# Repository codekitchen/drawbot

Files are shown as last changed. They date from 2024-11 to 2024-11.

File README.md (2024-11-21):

# Drawbot Remix

For [Recurse F2'24](https://www.recurse.com).

My goal is to build a wall-drawing robot, specifically to draw on our windows with dry-erase markers. This is starting out as a remix of [this drawbot project](https://github.com/andywise/drawbot) with some inspiration from [this other project](https://tinkerlog.com/2011/09/02/der-kritzler/).

I'm using some hardware I already have on hand, and I'm otherwise buying some different hardware from what was used in the original drawbot project, so the project will necessarily branch from the original drawbot project.

I've ended up making my own models for some of the 3D printed parts to match my needs. Those can be found in the [models](models/) folder in parameterized [OpenSCAD](https://openscad.org/) format.

I also ended up writing all my own software for the project, rather than using any of the software from the original drawbot. Just for fun!

## Progress

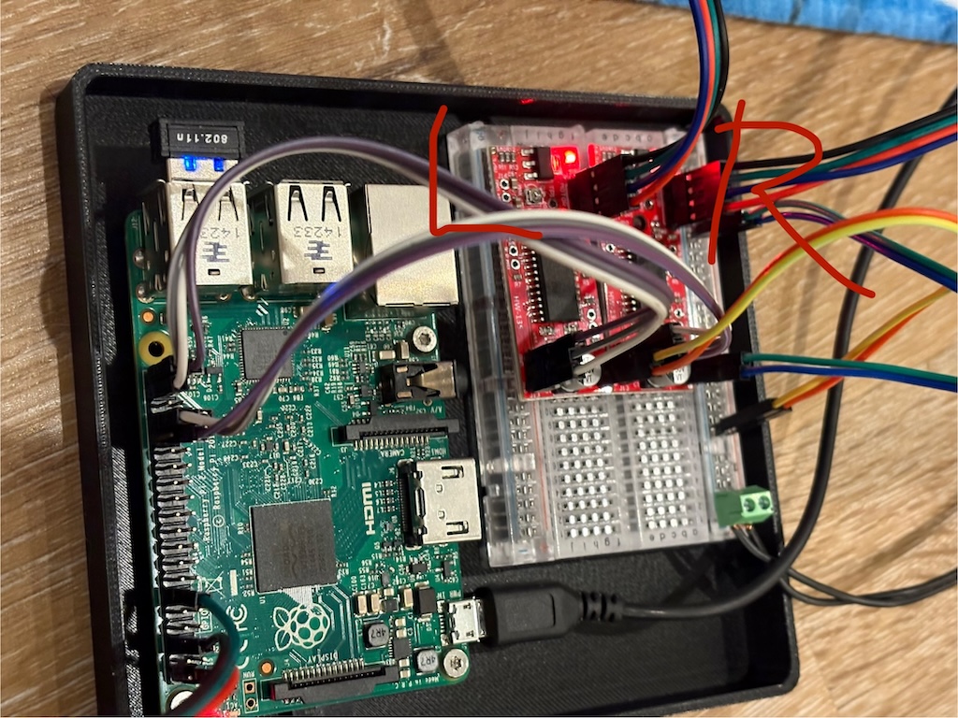
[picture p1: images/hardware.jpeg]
hardware


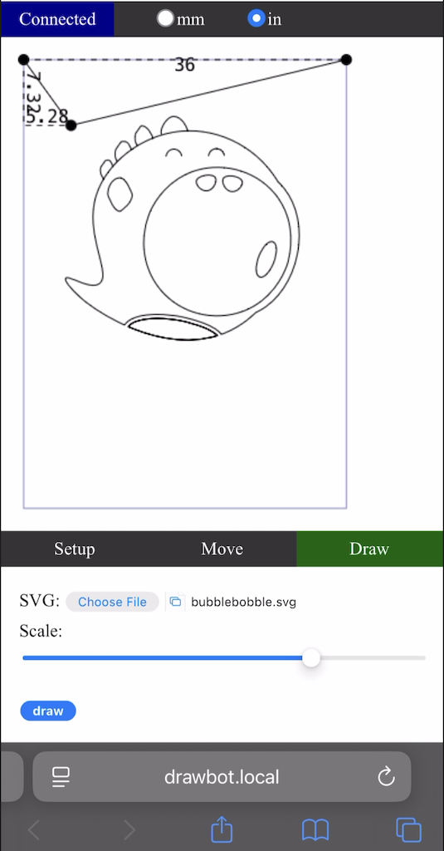
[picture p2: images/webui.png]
ui screenshot


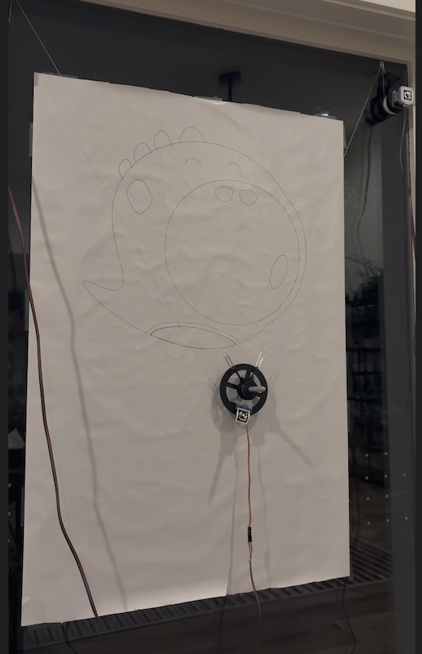
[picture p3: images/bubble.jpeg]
crow on window


I'm keeping a journal in a [separate document](JOURNAL.md).

## Links

- [Drawbot on GitHub](https://github.com/andywise/drawbot)
- [Drawbot assembly details](https://www.instructables.com/Drawbot/)
- [OpenSCAD Cheat Sheet](https://openscad.org/cheatsheet/)
- [NEMA-17 motor dimensions](https://reprap.org/wiki/NEMA_17_Stepper_motor)
- [Hull operations](https://hackaday.com/2018/02/13/openscad-tieing-it-together-with-hull/) for OpenSCAD modeling

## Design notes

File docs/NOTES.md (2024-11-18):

# Setup

1. Attach the motors to the top left/right of the surface using the suction cups.
2. Attach motor cables to controllers and motors.
3. Power up the controllers. WARNING: Don't do this before the cables are attached.
4. Attach the pen gantry to the strings. I like to tie the strings to paper clips and hook the clips to the pen gantry, it's a lot easier to detach after.
5. Attach the servo motor cable.
6. Turn on the pi.
7. Press the "pen up" button in the web ui.
8. Insert the pen so that it just barely isn't touching the surface, then tighten the screw to secure it in place.
9. Start drawing!

# Teardown

Reverse order of setup.

# Apriltag Detection

- [Webcam to JPEG](https://medium.com/@arpit23sh/capturing-webcam-images-using-html-and-javascript-9b8896ef1705)
- [emscripten compiling](https://emscripten.org/docs/getting_started/FAQ.html#faq-dead-code-elimination)
- [focal length](https://www.scantips.com/lights/subjectdistance.html)
-
image 5712 x 4284
focal len equiv: 26
focal len: 5.96
26/5.96 = 4.362 crop factor
35mm = 36 x 24, diagonal 43.2667 mm
43.2667 / 4.362 = 9.919 diagonal mm
diag = sqrt(5712**2+4284**2) = 7140
5712 / 7140 = 0.8
4284 / 7140 = 0.6
sensor width  = 9.919 * 0.8 = 7.93
sensor height = 9.919 * 0.6 = 5.95

focal length in pixels = (image width in pixels) * (focal length in mm) / (CCD width in mm)
fx = 5712 * 5.96 / 7.93 = 4293
fy = 4284 * 5.96 / 5.95 = 4291

# Pen Movement

## Motor Stepping

Spool diameter = 48mm
Spool circumference, distance moved in one full rotation = 48*PI = 150.79
Motor steps per rotation = 1600
Distance per step = 15.708 / 1600 = 0.0098175
Steps per mm = 101.8589

with string = 50*PI = 157

1600 steps = 155mm
Steps per mm = 10

d = 400.05
x = 60.32
y = 88.9

h1 = 107.43
h2 = 351

# new position
x=200
y=90
h1 = 220
h2 = 220

h1' = 220-107 = 113
h2' = 220-351 = -131

250,200
350,400

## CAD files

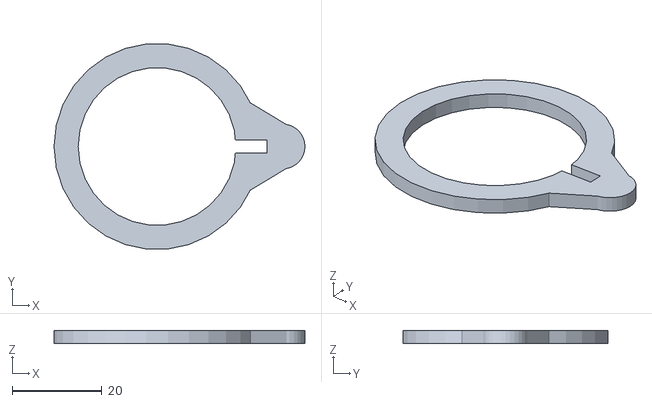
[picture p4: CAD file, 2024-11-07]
models/drawbot_stls/BearingConnector.stl
56.0 x 45.7 x 3.00

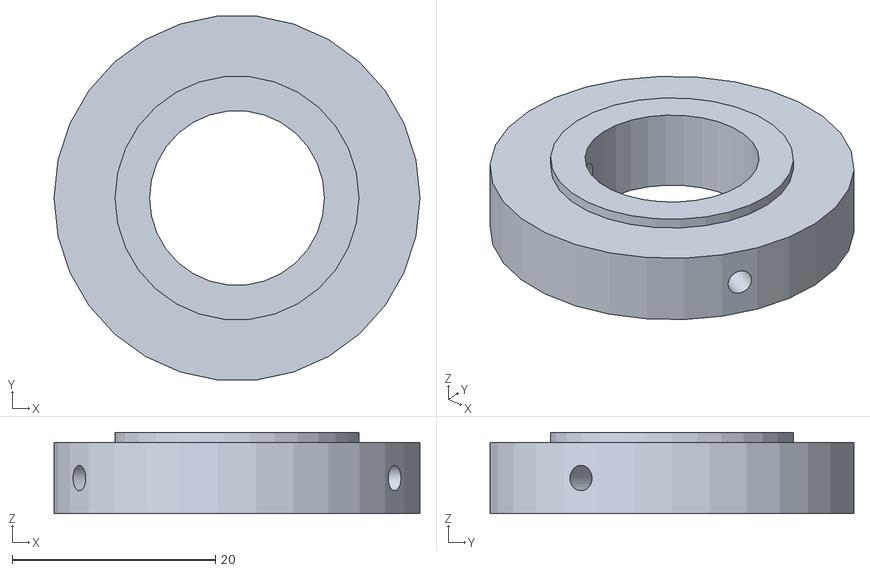
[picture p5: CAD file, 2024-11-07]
models/drawbot_stls/PolargraphGondola-retainer.stl
36.0 x 35.8 x 8.00

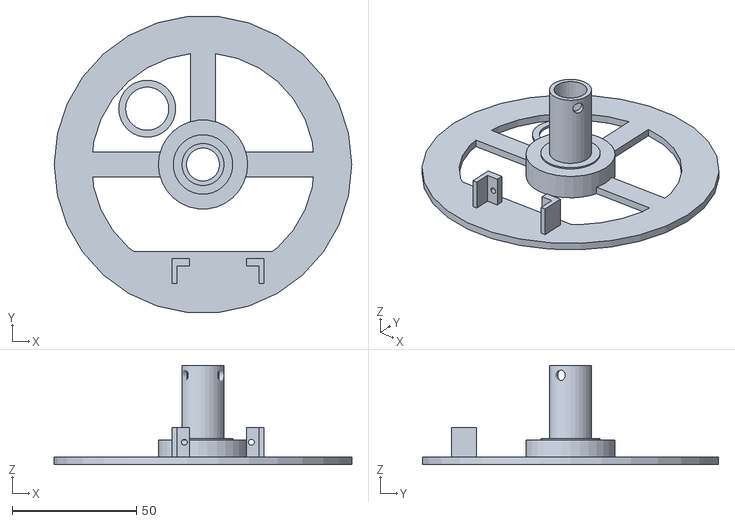
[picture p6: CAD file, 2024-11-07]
models/drawbot_stls/PolargraphGondola.stl
120.0 x 119.3 x 40.0

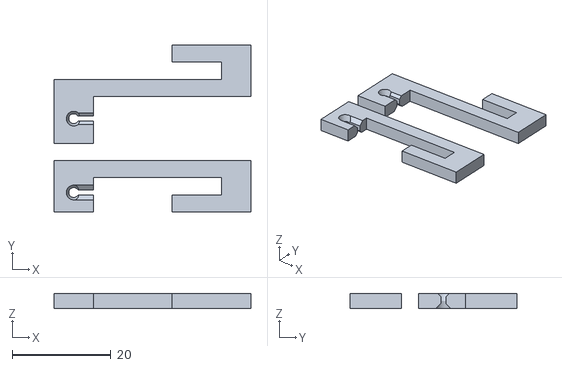
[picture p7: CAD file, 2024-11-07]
models/drawbot_stls/BearingConnectorArms.stl
40.0 x 34.0 x 3.00

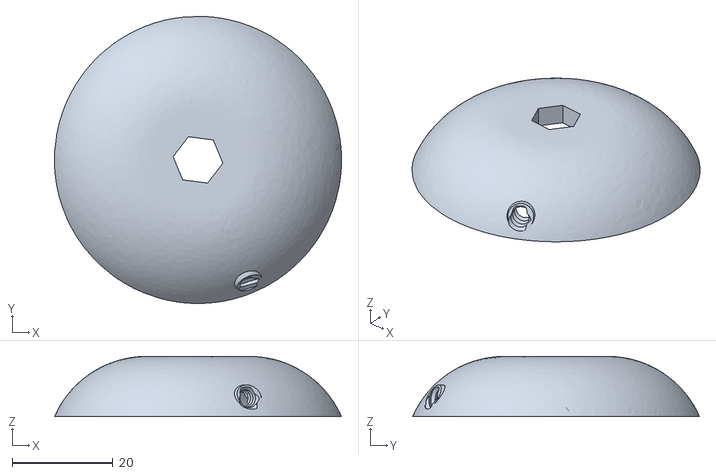
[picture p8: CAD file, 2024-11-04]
models/drawbot_stls/SuctionDomeHole.stl
57.1 x 57.1 x 12.0

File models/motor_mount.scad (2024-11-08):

// Motor Mount
motor_width=42.3; // NEMA-17 motor width
shaft_diam=25;
bolthole_dist=31.0; // NEMA-17 bolt hole pattern
plate_width=motor_width*1.3;

thickness=4;

use <spool.scad>
use <scad_libs/hulls.scad>

/* [Hidden] */
$fn=100;

difference(){
    // base plate with no holes
    sequentialHull(){
        // plate
        cylinder(d=plate_width, h=thickness);
        // plate edge
        translate([-plate_width/2,plate_width/2])
            cube([plate_width,0.1,thickness]);
        // mount edge
        translate([-mount.x/2,mount_point-mount.y,0])
            cube([mount.x,0.1,mount.z]);
        // mount body
        mount_body();
    }

    // plate holes for shaft and screws
    translate([0,0,-1]) {
        cylinder(d=shaft_diam, h=thickness+2);
        bd=bolthole_dist/2;
        for (x=[-bd,bd],y=[-bd,bd]) {
            translate([x,y]) {
                // screw hole
                cylinder(d=3.5, h=thickness+2);
                // screw head inset
                translate([0,0,2.5]) cylinder(d=8, h=thickness);
            }
        }
    }
    // large groove in mount
    mount_groove();
    // pin hole for suction cup
    mount_pinhole();
}

mount_point=70;
mount = [12,25,25];
mount_rounding_r=4.5;
pin_hole_r = 1.9;
mount_pin = [0,4.5+pin_hole_r,9.5]; // pin hole distance from edges
groove_y=12;
groove_width=8;

// the part that mounts to the suction cup
module mount_body() {
    translate([0,mount_point-mount.y,mount.z/2]) rotate([0,90,0])
    linear_extrude(height=mount.x, center=true) {
        hull() {
            yend=mount.y-mount_rounding_r;
            translate([-mount.z/2,0]) square([mount.z, yend]);

            xoff=mount.z/2-mount_rounding_r;
            for (x=[-xoff,xoff]) {
                translate([x,yend])
                    circle(r=mount_rounding_r);
            }
        }
    }
}

module mount_pinhole() {
    translate([0,mount_point-mount.y,mount.z/2]) rotate([0,90,0])
    linear_extrude(height=mount.x+2, center=true) {
        translate([-(mount.z/2)+mount_pin.z, mount.y-mount_pin.y]) circle(r=pin_hole_r);
    }
}

// the big vertical groove so the suction cup arm can swing back and forth
module mount_groove() {
    translate([0,mount_point-groove_y,mount.z/2])
    linear_extrude(height=mount.z+2, center=true) {
        circle(d=groove_width);
        translate([0,10,0]) square([groove_width,20], center=true);
    }
}

// integration testing, show all the other joined components
*color("silver") {
    motor=[motor_width,motor_width,37];
    suction_cup=[62,62,13.5];

    // motor
    translate([0,0,-motor.z/2]){
        cube(motor,center=true);
        translate([0,0,motor.z/2]) cylinder(d=5,h=22);
    }

    // spool from other file
    translate([0,0,20+thickness])
    spool();

    // suction cup stand-in
    suction_cup_arm=13.5;
    suction_cup_hole=9.5;
    translate([0,mount_point-mount_pin.y,mount.z]) {
        cylinder(d=suction_cup.x,h=suction_cup.z);
        difference() {
            translate([0,0,-suction_cup_arm]) cylinder(d=3,h=suction_cup_arm);
            translate([0,0,-suction_cup_hole]) rotate([0,90,0]) cylinder(d=2, h=10, center=true);
        }
    }
}

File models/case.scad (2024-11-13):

box = [110, 125, 12];
corner_r = 5;
wall_thickness = 1.5;
bottom_thickness = 1;
post_offset = 5;
screw_size = 2.6;
pi_offs = [20,5];

module cpus() {
  translate([pi_offs.x,pi_offs.y,8.5])
  import("rPi2_01.stl");
  // breadboard
  translate([5, 70, 5])
  cube([82, 55, 10]);
  // motor controllers
  translate([5, 70+55/2-10, 15])
  cube([100, 20, 2]);
}
*cpus();

linear_extrude(box.z)
translate([wall_thickness, wall_thickness])
difference() {
  offset(corner_r) square([box.x, box.y]);
  offset(corner_r-wall_thickness)
  translate([wall_thickness/2, wall_thickness/2])
    square([box.x-wall_thickness, box.y-wall_thickness]);
}

linear_extrude(bottom_thickness)
translate([wall_thickness, wall_thickness])
offset(corner_r) square([box.x, box.y]);

posts=[[23.5,3.5],[81.5,3.5],[23.5,52.5],[81.5,52.5]];
for (p = posts) {
  translate([pi_offs.x+p.x,pi_offs.y+p.y,bottom_thickness]) difference() {
    $fn=50;
    cylinder(h=post_offset, r=2.5);
    cylinder(h=post_offset+1, d=screw_size);
  }
}

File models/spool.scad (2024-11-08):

/* [Spool] */
diameter=56;
inner_diameter=48;
width=20;
inner_width=10;
axle_diameter=10.5;

/* [Flange] */
flange_diameter=23;
bolthole_spacing=8.0;
bolthole_diameter=3.1;

module spool() {
    $fn=100;
    difference() {
    // spool body
    union() {
        // inner rim
        cylinder(h=inner_width, d=inner_diameter, center=true);
        // sloping sides
        translate([0,0,(inner_width/2)+(width-inner_width)/4])
            cylinder(h=(width-inner_width)/2, d2=diameter, d1=inner_diameter, center=true);
        translate([0,0,-((inner_width/2)+(width-inner_width)/4)])
            cylinder(h=(width-inner_width)/2, d1=diameter, d2=inner_diameter, center=true);
    }
    // axle hole
    cylinder(h=width*2,d=axle_diameter,center=true);
    // thread hole
    rotate([90,0,0])
    cylinder(h=diameter+2,d=inner_width/4,center=true);
    // flange bed
    translate([0,0,width/2])
    cylinder(h=width-inner_width, d=flange_diameter,center=true);
    // flange bed
    translate([0,0,-width/2])
    cylinder(h=width-inner_width, d=flange_diameter,center=true);
    // screw holes
    rotate(45) // avoid lining up with thread hole
    for (r=[0:3]) {
            rotate(r*90)
            translate([bolthole_spacing,0])
            cylinder(h=width*2, d=bolthole_diameter, center=true);
    }
    }
}

spool();

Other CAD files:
models/scad_libs/hulls.scad

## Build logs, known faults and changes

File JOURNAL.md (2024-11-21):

# Project Journal

# 2024-11-17

I did a lot of polish to the web ui, and made some improvements to drawing accuracy as well.

The web ui now shows a preview of what it's going to draw, and you can resize and move the drawing around to where you want it to be drawn in relation to the motors and current pen location.

I've added some [NOTES](docs/NOTES.md) and [TODOs](docs/TODO.md).

I am finding that when the pen descends more than about 1 meter below the motors, it starts losing tension against the surface and sometimes pulling away and not drawing. I think I'd probably need to add something to tension it from the bottom to get it working better at that distance.

bubble bobble drawing

web ui

# 2024-11-14

The new motor controllers are here, soldered, and wired up. After a couple practice runs, I figured out how to fabricate the motor cables I needed, as well. It took a few attempts for me to get the JST PH connectors tight, they're tricky.

We tested out a custom .svg on one of our larger windows. I am very happy with the precision, I wasn't sure I'd be able to get closely spaced lines to be so crisp.

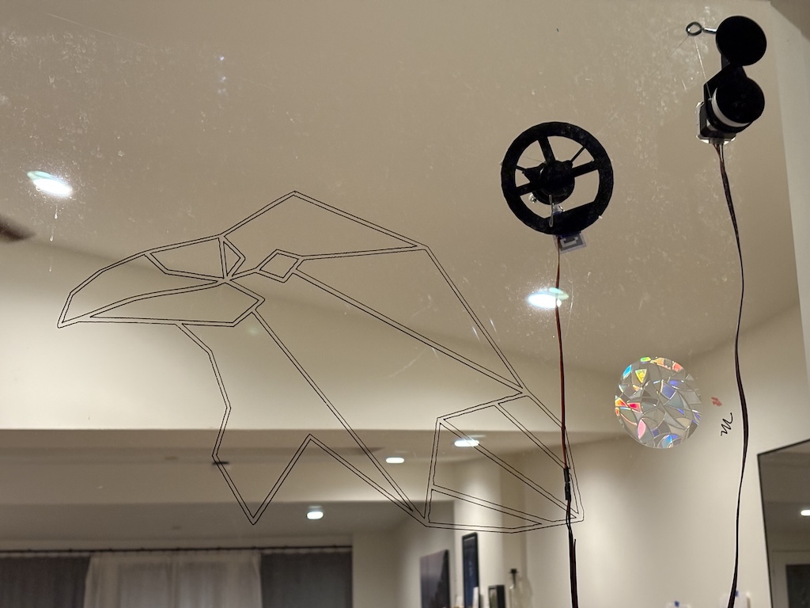
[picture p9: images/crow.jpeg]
drawbot drew a crow


# 2024-11-12

I needed to fabricate some longer 3 meter cables for the stepper motors. My first attempt did not end well, one of the cables ended up shorting out and frying both motor controllers. Fortunately nothing else seems broken. But I'm going to have to wait a couple days for replacement parts.

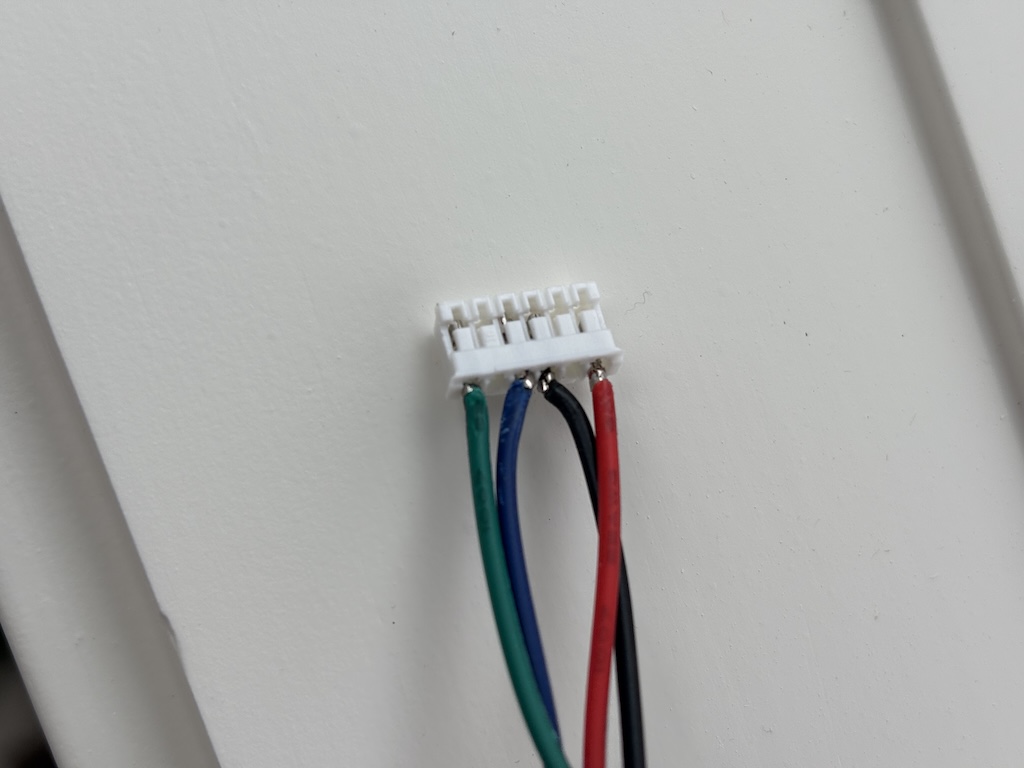
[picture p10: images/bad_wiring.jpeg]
bad wiring job


## 2024-11-11

Drawing a triforce!

drawing a triforce

This is a hard-coded list of points. Next steps:

* Parse SVG to draw commands.
* Allow scaling and translation of the SVG commands to fit the desired space.
* Lifting the pen. I'm waiting on some hardware parts for this one.

The apriltag calibration setup works pretty well, but my y distance calculation is a little bit off somewhere. Safari on iOS makes the UX a little rough, sadly. If you take a photo directly in the browser, it doesn't include the EXIF data. So you have to take a photo in the photos app, then switch over to the browser and upload it. 😮‍💨

## 2024-11-08

I got a chance to brush off my rusty trig skills and figured out how to map moving between (x,y) coordinates into rotations of the two motors.

Then I started in on the actual web UI. The backend is written in Go. I plan to keep most of the smarts in the browser, the backend will just execute simple draw commands and persist state to disk. I got enough done on that today to enable manual etch-a-sketch style drawing.

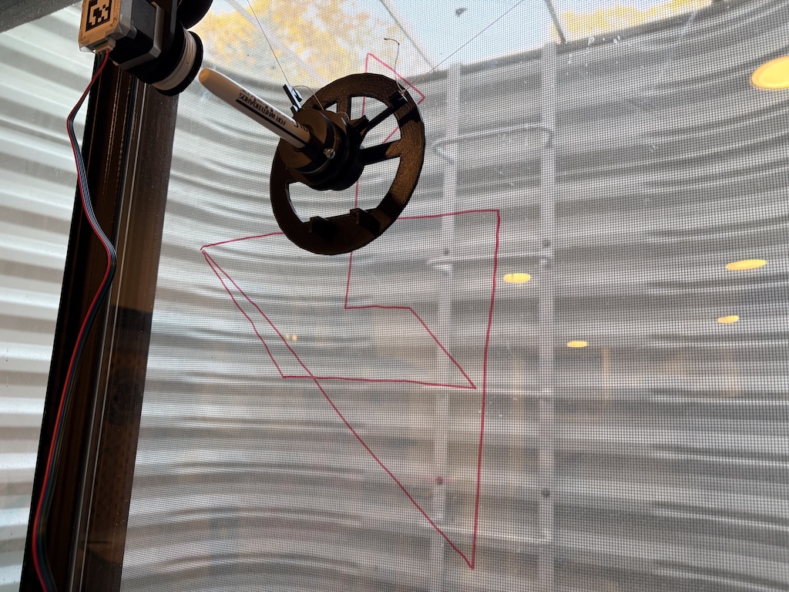
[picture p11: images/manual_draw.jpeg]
manual drawing


## 2024-11-08

I went down a rabbit hole of using AprilTags to automatically calibrate the robot with the positions of the motors and pen. I have a proof-of-concept compiling the [apriltag C library](https://github.com/AprilRobotics/apriltag) to WebAssembly so that the whole process can happen client-side in the browser UI. It was difficult working out how to get the camera focal length in pixels using just EXIF data, but I have something that is working well at least for iPhone cameras.

I put an apriltag on each motor, placed them 350cm apart, and I get a very accurate reading from a photo taken right in the browser:

apriltag proof-of-concept

## 2024-11-07

The robot is fully printed and moving! This is just a simple [python test script](motor-test.py). Now it's time to start on the actual drawing software. I realized I need some thinner dry-erase markers, I'm having trouble finding that locally so I have some arriving today or tomorrow.

robot moving on window

I had to order another pair of motor driver boards, one of the pair I received was broken. I've also ordered the tools and parts I need to make longer stepper motor cables, they need to be at least 3 meters long to draw on the windows I'm planning to use this on.

I modified the motor mount so that the spool no longer rubs against the wall/window as the bot is running. It is a huge win to pull in all the connecting components as "ghosts" in the OpenSCAD model, so you can preview exactly how everything will fit together.

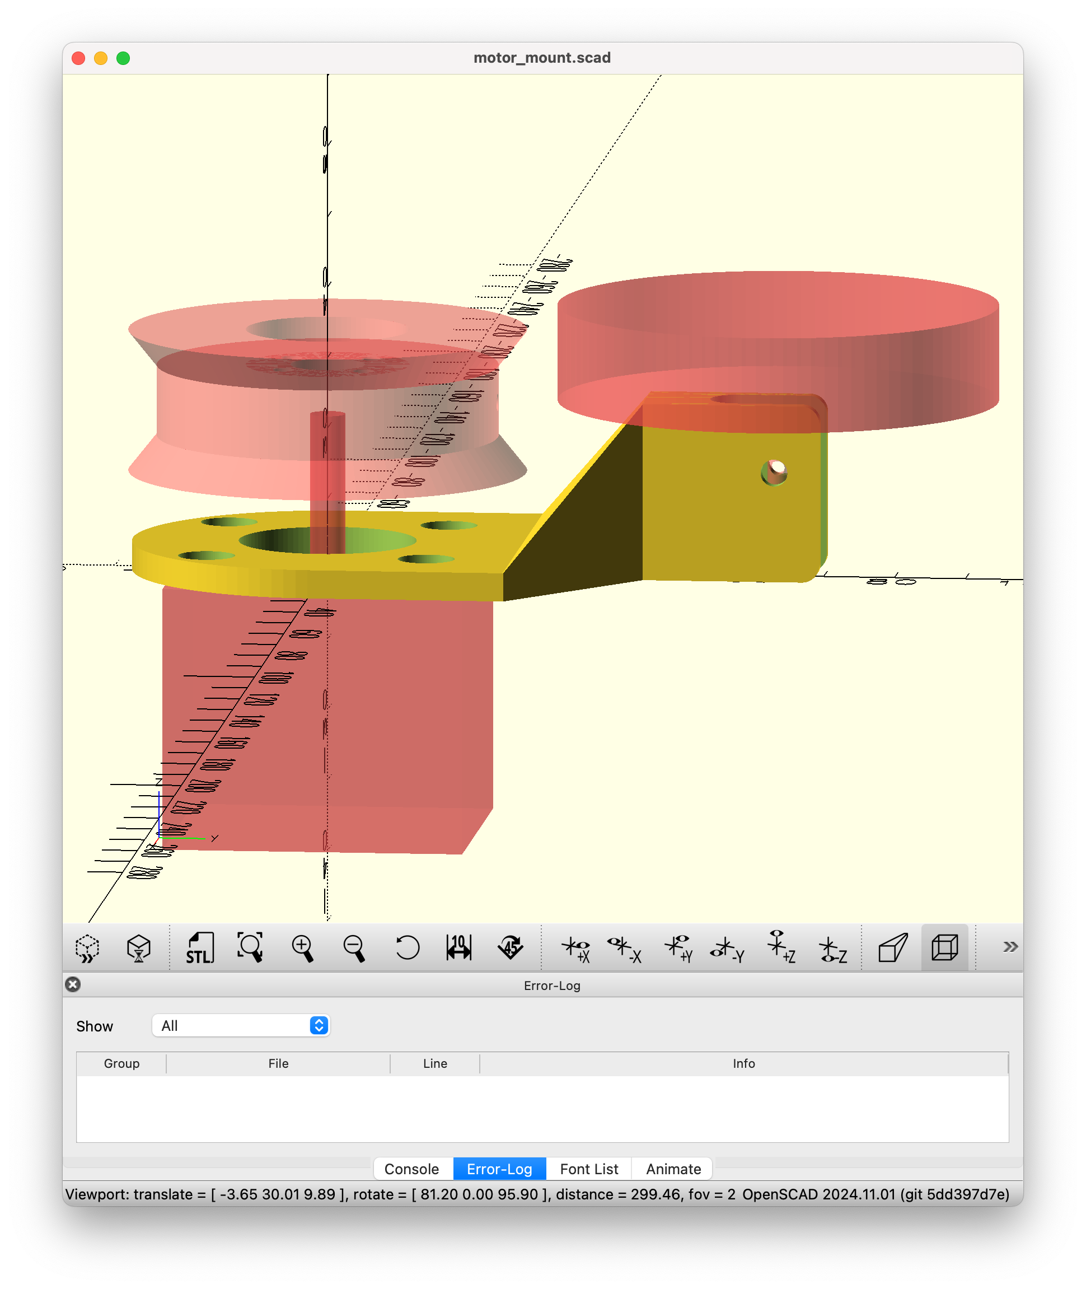
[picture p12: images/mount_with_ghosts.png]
openscad model showing ghosts


## 2024-11-04

The exact suction cups used in the original drawbot are no longer available. I found some similar ones online, but I have to modify the motor mount piece to allow for the slightly shorter suction cup stem.

Rather than stripping USB cables to wire up the motors, I'm going to try using some extra ethernet cable that I have lying around. I think it should be able to handle the current.

I have a raspberry pi 2 that was retired from another project, I'm going to use that rather than the pi zero.

The NEMA 17 motors I already have on hand look very similar on the spec sheets, I'm going to try using them.

New [spool](models/spool.scad) and [motor mount](models/motor_mount.scad) designs.

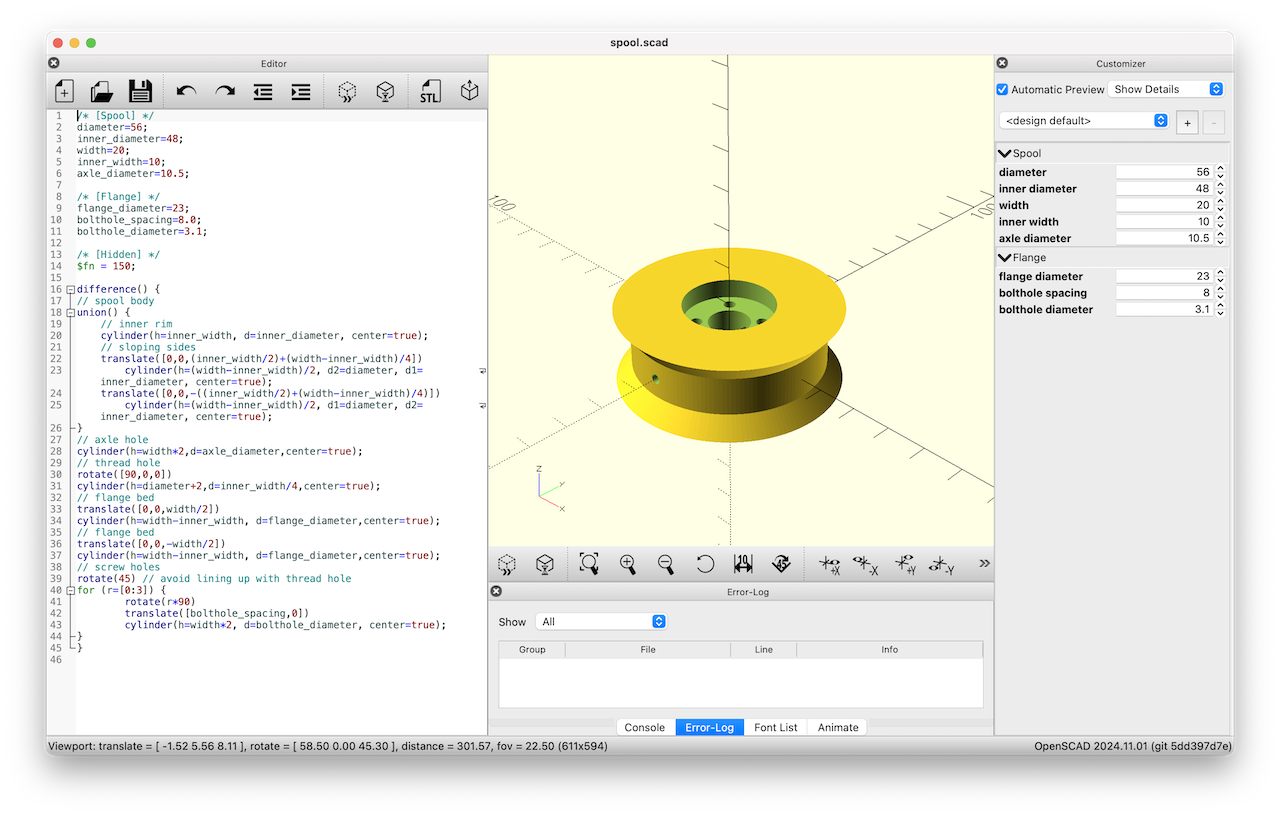
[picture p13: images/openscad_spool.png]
spool in OpenSCAD

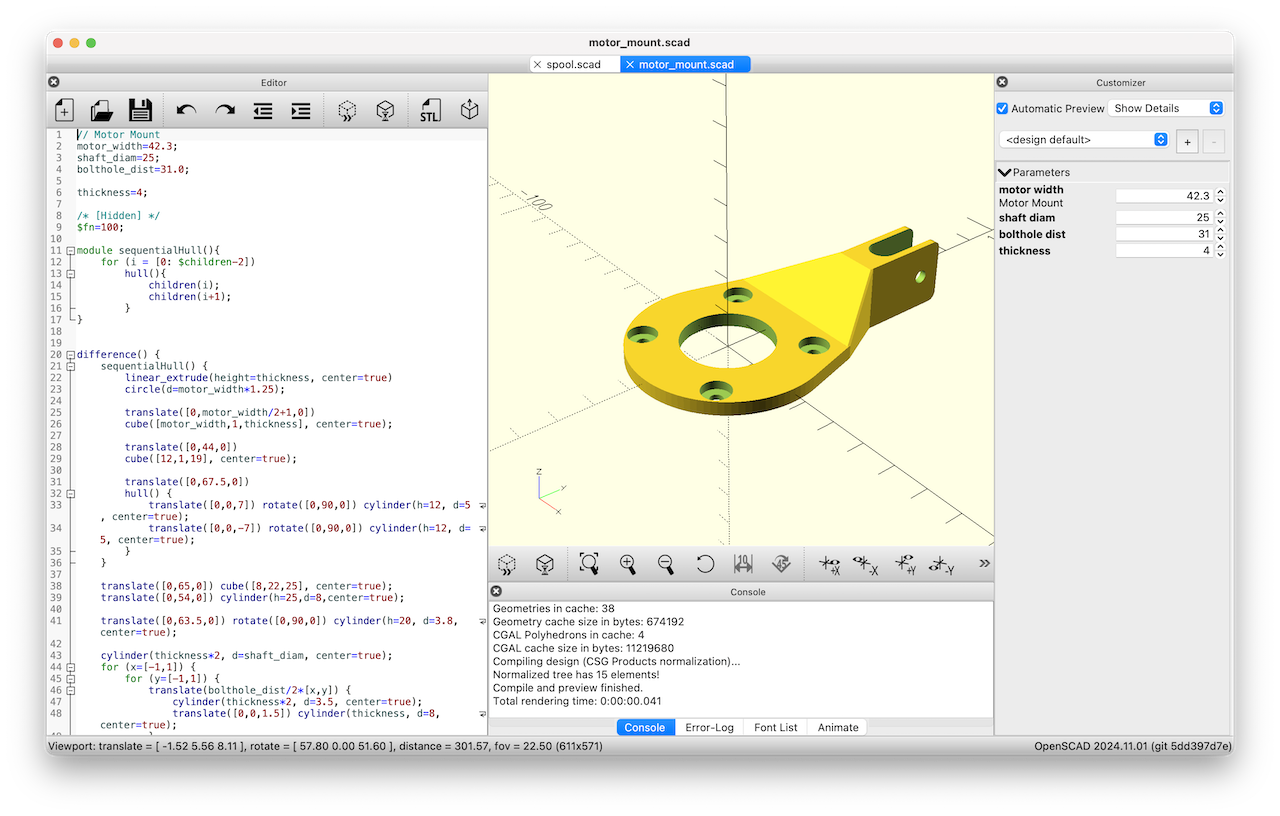
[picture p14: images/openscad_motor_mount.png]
motor mount in OpenSCAD


Testing the mount on a window:

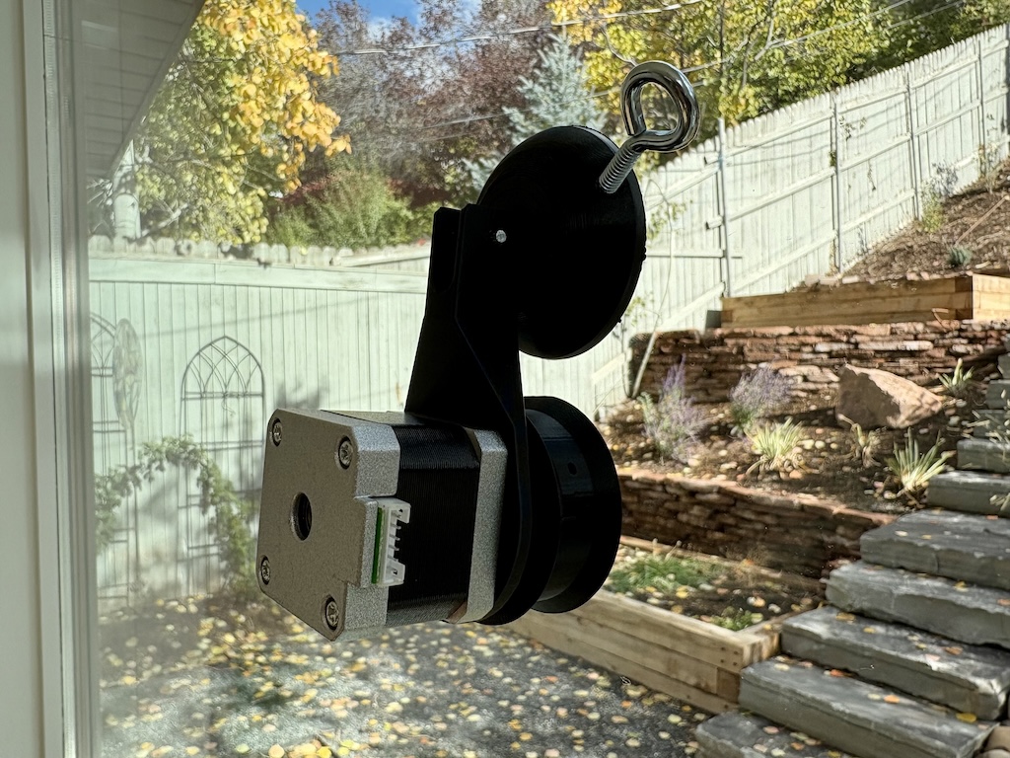
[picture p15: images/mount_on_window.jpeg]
motor assembly on window


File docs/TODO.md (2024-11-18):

# UI

- [x] mobile zooming then can't unzoom
- [x] draw all paths in svg, not just first path
- [x] scale vertical so you can see the bottom of draw area (or scroll?)
- [x] show pen up/down buttons again
- [ ] show visual feedback for joystick movement
- [ ] show warning/error if drawing is out of bounds

# Hardware

- [ ] solenoid for lifting off the surface instead of servo
- [ ] barrel jack for motor power so it can be disconnected
- [ ] some way to keep tension against the window when the pen moves further down from the top motors

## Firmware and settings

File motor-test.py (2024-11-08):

#!/usr/bin/env python

# Import required modules
import time
import RPi.GPIO as GPIO

GPIO.setmode(GPIO.BCM)

RDIR=20
RSTE=21
LDIR=6
LSTE=13
STEPS=1600

# LDIR=False = pull in
# RDIR=False = push out

GPIO.setup(RDIR, GPIO.OUT)
GPIO.setup(RSTE, GPIO.OUT)
GPIO.setup(LDIR, GPIO.OUT)
GPIO.setup(LSTE, GPIO.OUT)

def move(mdir, mste, d, nsteps):
    GPIO.output(mdir, d)
    for i in range(nsteps):
        GPIO.output(mste, True)
        time.sleep(0.001)
        GPIO.output(mste, False)
        time.sleep(0.001)

move(LDIR, LSTE, True, 1130)
move(RDIR, RSTE, True, 1310)

#move(RDIR, RSTE, False, 200)
#move(RDIR, RSTE, True, 200)

def run():
    for i in range(STEPS):
        GPIO.output(RSTE, True)
        GPIO.output(LSTE, True)
        time.sleep(0.001)
        GPIO.output(RSTE, False)
        GPIO.output(LSTE, False)
        time.sleep(0.001)

#GPIO.output(RDIR, True)
#GPIO.output(LDIR, False)
#run()

#GPIO.output(RDIR, False)
#GPIO.output(LDIR, True)
#run()

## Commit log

2024-11-04 first update
    [SuctionDomeHole.stl, motor_mount.scad, spool.scad]
2024-11-07 add other drawbot stls used
    [BearingConnector.stl, BearingConnectorArms.stl, PolargraphGondola-retainer.stl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]
2024-11-08 updated motor mount
    [hulls.scad, motor_mount.scad, spool.scad]
2024-11-13 simple case design
    [case.scad]
2024-11-16 throttle update messages
2024-11-17 restore pen up/down buttons
